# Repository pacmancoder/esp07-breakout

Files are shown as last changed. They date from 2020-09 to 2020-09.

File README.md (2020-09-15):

# esp07-breakout
Crude ESP-07 module breakout board intended for toner transfer method DIY PCB production.

Use [Mirrored_Front_Layer.svg](Mirrored_Front_Layer.svg) file for printing with 100% scale;  No additional mirroring required.
Also 2 additional *almost* parallel jumper wires should be placed on the backside of the PCB.

|Render |Photo |
|---|---|
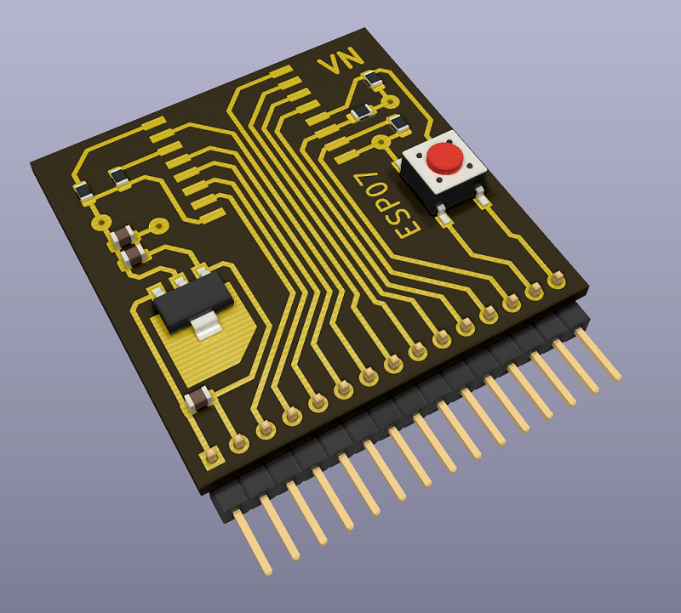
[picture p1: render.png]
Render
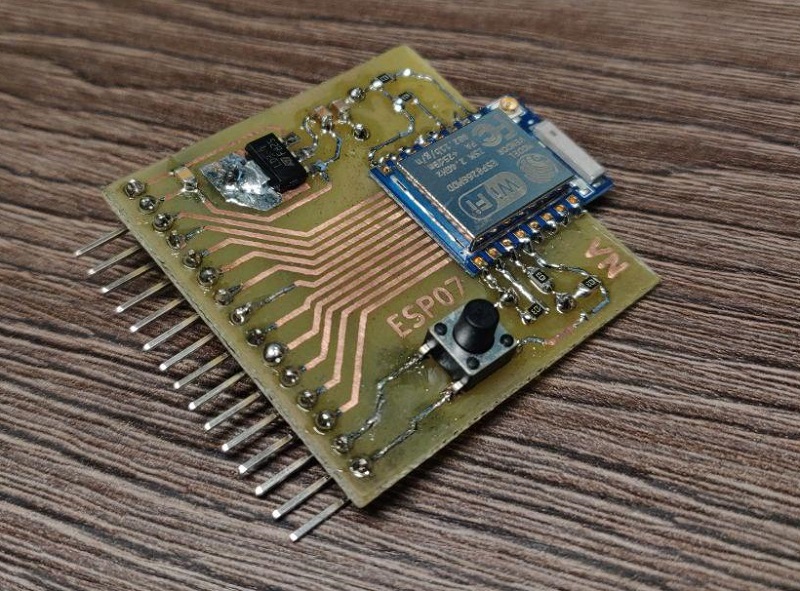
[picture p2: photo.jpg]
|||

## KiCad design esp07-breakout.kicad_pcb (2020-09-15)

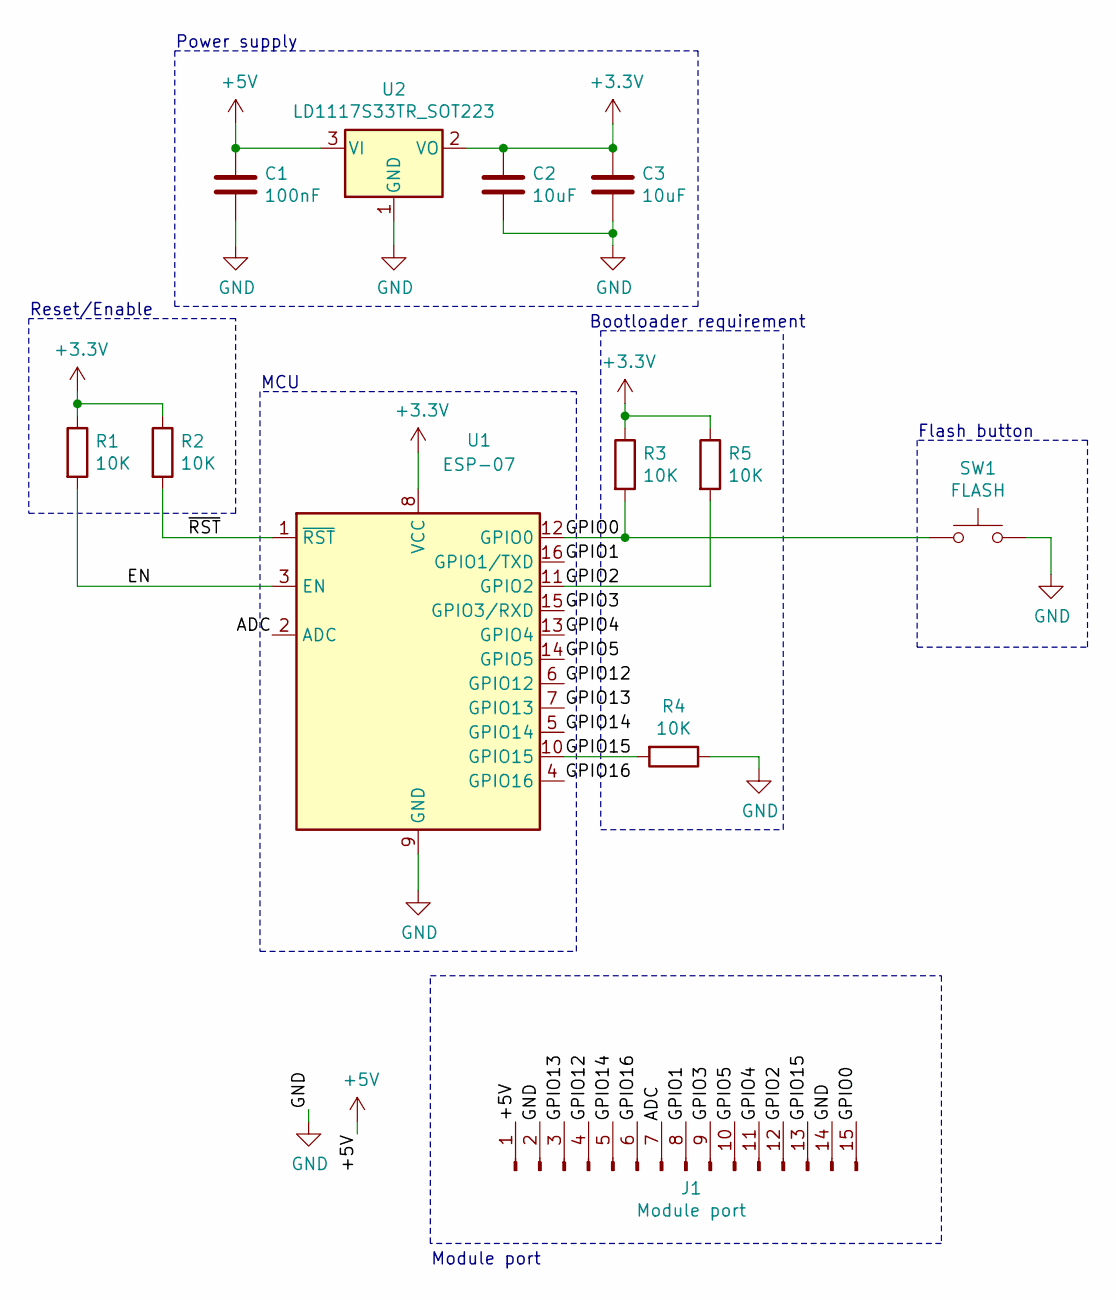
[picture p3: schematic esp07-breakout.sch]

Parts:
C1: 100nF; C_0805_2012Metric_Pad1.15x1.40mm_HandSolder
C2, C3: 10uF; C_0805_2012Metric_Pad1.15x1.40mm_HandSolder
J1: Module port; PinHeader_1x15_P2.54mm_Horizontal
R1, R2, R3, R4, R5: 10K; R_0805_2012Metric_Pad1.15x1.40mm_HandSolder
SW1: FLASH; SW_SPST_PTS645
U1: ESP-07
U2: LD1117S33TR_SOT223; SOT-223-3_TabPin2

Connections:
+3V3: C2.1, C3.1, R1.1, R2.1, R3.1, R5.1, U1.8 (VCC), U2.2 (VO)
+5V: C1.1, J1.1, U2.3 (VI)
/ADC: J1.7, U1.2 (ADC)
/EN: R1.2, U1.3 (EN)
/GPIO0: J1.15, R3.2, SW1.1, U1.12 (GPIO0)
/GPIO1: J1.8, U1.16 (GPIO1/TXD)
/GPIO2: J1.12, R5.2, U1.11 (GPIO2)
/GPIO3: J1.9, U1.15 (GPIO3/RXD)
/GPIO4: J1.11, U1.13 (GPIO4)
/GPIO5: J1.10, U1.14 (GPIO5)
/GPIO12: J1.4, U1.6 (GPIO12)
/GPIO13: J1.3, U1.7 (GPIO13)
/GPIO14: J1.5, U1.5 (GPIO14)
/GPIO15: J1.13, R4.2, U1.10 (GPIO15)
/GPIO16: J1.6, U1.4 (GPIO16)
/~RST: R2.2, U1.1 (~RST)
GND: C1.2, C2.2, C3.2, J1.2, J1.14, R4.1, SW1.2, U1.9 (GND), U2.1 (GND)

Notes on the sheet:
Power supply
Reset/Enable
Bootloader requirement
Flash button
Module port
MCU

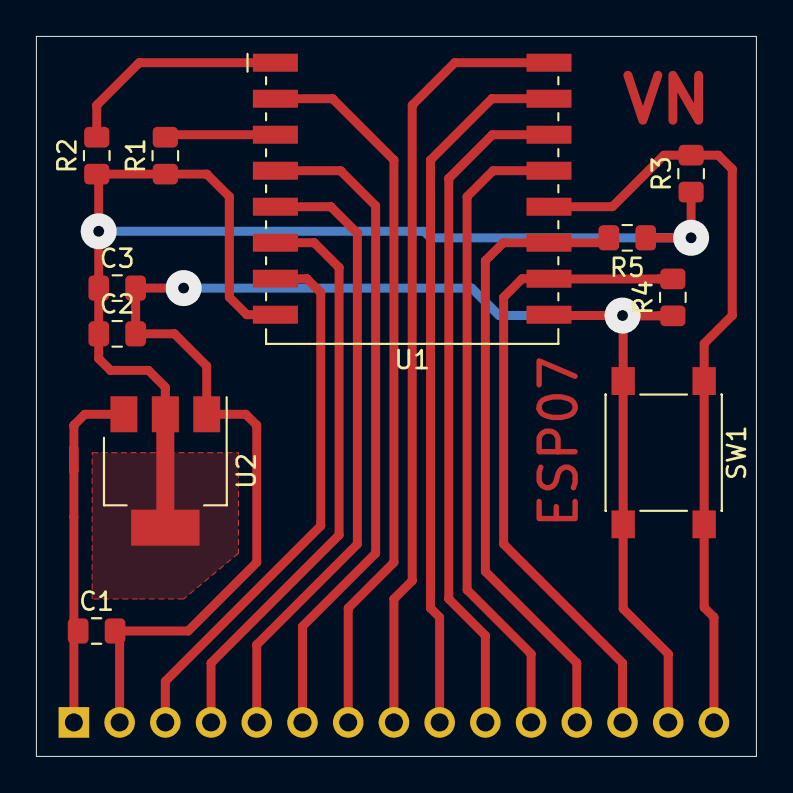
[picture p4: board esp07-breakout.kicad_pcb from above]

Board: 2 copper layers, 40.0 x 40.0 mm, 12 parts (1 on the bottom side), 17 nets.

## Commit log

2020-09-14 Developed schematics and routed the board; Prepared production file
    [esp07-breakout.kicad_pcb, esp07-breakout.sch]
2020-09-15 Added back layer silkscreen (fixes #1); Added photo
    [esp07-breakout.kicad_pcb]
